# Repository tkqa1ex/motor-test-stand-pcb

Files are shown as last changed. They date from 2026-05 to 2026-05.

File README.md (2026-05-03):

# Motor Test Stand PCB

This repository contains the PCB design for a DC motor test stand.

## Features
- Current measurement (INA219 / ACS758)
- Temperature sensing (TMP117)
- Microcontroller interface (Arduino)

## Project Goal
Measure torque, efficiency, and electrical parameters of a DC motor using a generator-based load system.

## Files
- /pcb → PCB layout
- /schematic → circuit design
- /gerbers → manufacturing files

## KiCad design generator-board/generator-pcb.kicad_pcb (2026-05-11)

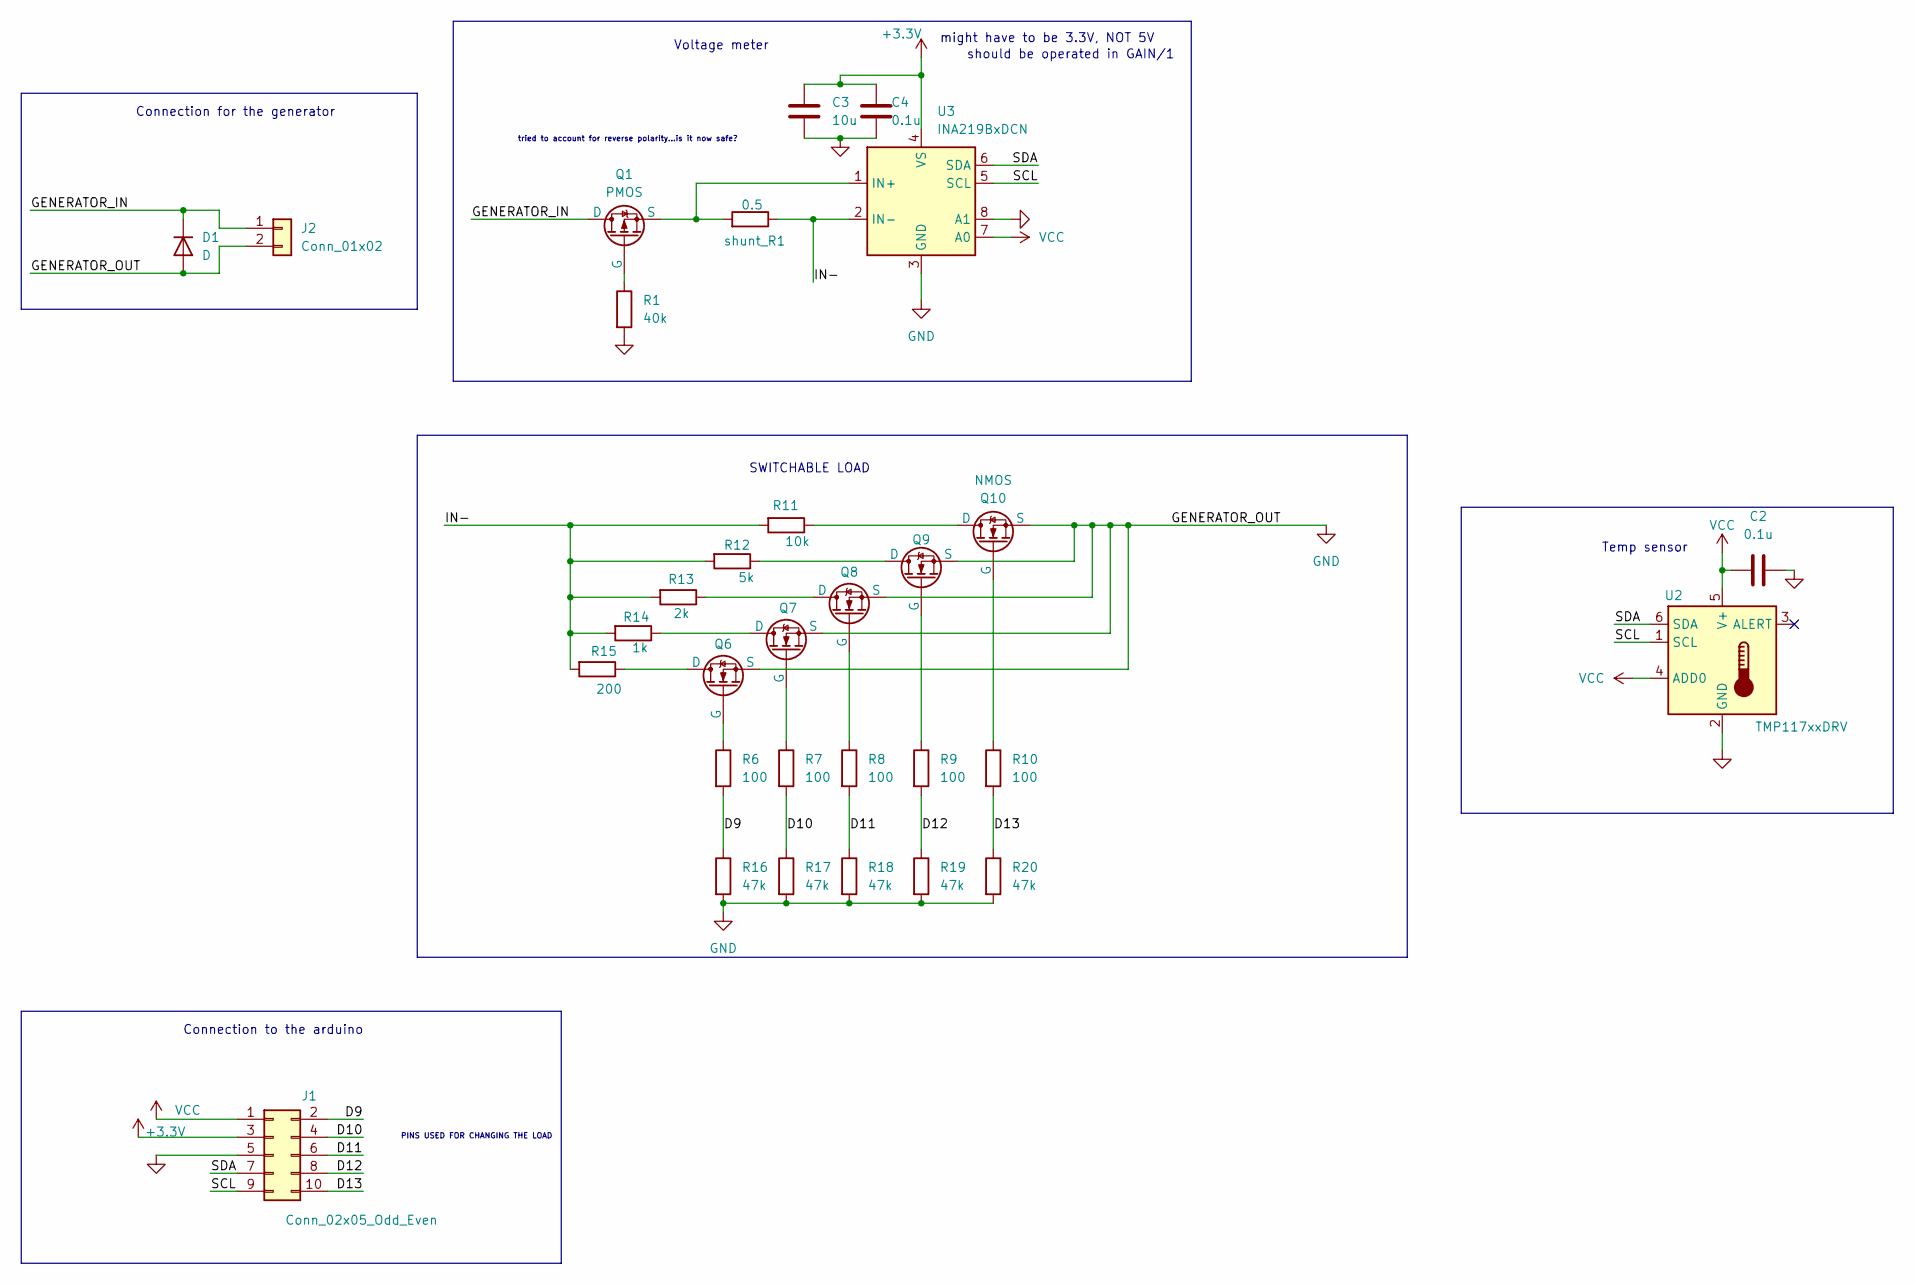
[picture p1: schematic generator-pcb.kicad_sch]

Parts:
C2, C4: 0.1u; CP_Radial_D10.0mm_P5.00mm
C3: 10u; CP_Radial_D10.0mm_P5.00mm
D1: D; D_DO-41_SOD81_P10.16mm_Horizontal
J1: Conn_02x05_Odd_Even; PinHeader_2x05_P2.54mm_Vertical
J2: Conn_01x02; PinHeader_1x02_P2.54mm_Vertical
Q1: PMOS; TO-220-3_Vertical
Q6, Q7, Q8, Q9, Q10: NMOS; TO-220-3_Vertical
R1: 40k; R_Axial_DIN0207_L6.3mm_D2.5mm_P7.62mm_Horizontal
R6, R7, R8, R9, R10: 100; R_Axial_DIN0207_L6.3mm_D2.5mm_P7.62mm_Horizontal
R11: 10k; R_Axial_DIN0207_L6.3mm_D2.5mm_P7.62mm_Horizontal
R12: 5k; R_Axial_DIN0207_L6.3mm_D2.5mm_P7.62mm_Horizontal
R13: 2k; R_Axial_DIN0207_L6.3mm_D2.5mm_P7.62mm_Horizontal
R14: 1k; R_Axial_DIN0207_L6.3mm_D2.5mm_P7.62mm_Horizontal
R15: 200; R_Axial_DIN0207_L6.3mm_D2.5mm_P7.62mm_Horizontal
R16, R17, R18, R19, R20: 47k; R_Axial_DIN0207_L6.3mm_D2.5mm_P7.62mm_Horizontal
U2: TMP117xxDRV; WSON-6-1EP_2x2mm_P0.65mm_EP1x1.6mm
U3: INA219BxDCN; SOT-23-8
shunt_R1: 0.5; R_Axial_DIN0207_L6.3mm_D2.5mm_P10.16mm_Horizontal

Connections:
+3.3V: C3.1, C4.1, J1.3, U3.4 (VS)
/D9: J1.2, R6.2, R16.1
/D10: J1.4, R7.2, R17.1
/D11: J1.6, R8.2, R18.1
/D12: J1.8, R9.2, R19.1
/D13: J1.10, R10.2, R20.1
/GENERATOR_IN: D1.1 (K), J2.1, Q1.1 (D)
/IN-: R11.2, R12.2, R13.2, R14.2, R15.2, U3.2 (IN-), shunt_R1.1
/SCL: J1.9, U2.1 (SCL), U3.5 (SCL)
/SDA: J1.7, U2.6 (SDA), U3.6 (SDA)
GND: C2.2, C3.2, C4.2, D1.2 (A), J1.5, J2.2, Q6.3 (S), Q7.3 (S), Q8.3 (S), Q9.3 (S), Q10.3 (S), R1.2, R16.2, R17.2, R18.2, R19.2, R20.2, U2.2 (GND), U3.3 (GND), U3.8 (A1)
unnamed: Q1.2 (G), R1.1
unnamed: Q1.3 (S), U3.1 (IN+), shunt_R1.2
unnamed: Q6.1 (D), R15.1
unnamed: Q6.2 (G), R6.1
unnamed: Q7.1 (D), R14.1
unnamed: Q7.2 (G), R7.1
unnamed: Q8.1 (D), R13.1
unnamed: Q8.2 (G), R8.1
unnamed: Q9.1 (D), R12.1
unnamed: Q9.2 (G), R9.1
unnamed: Q10.1 (D), R11.1
unnamed: Q10.2 (G), R10.1
VCC: C2.1, J1.1, U2.4 (ADD0), U2.5 (V+), U3.7 (A0)

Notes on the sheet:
Voltage meter
tried to account for reverse polarity...is it now safe?
might have to be 3.3V, NOT 5V
Temp sensor
SWITCHABLE LOAD
Connection for the generator
should be operated in GAIN/1
Connection to the arduino
PINS USED FOR CHANGING THE LOAD

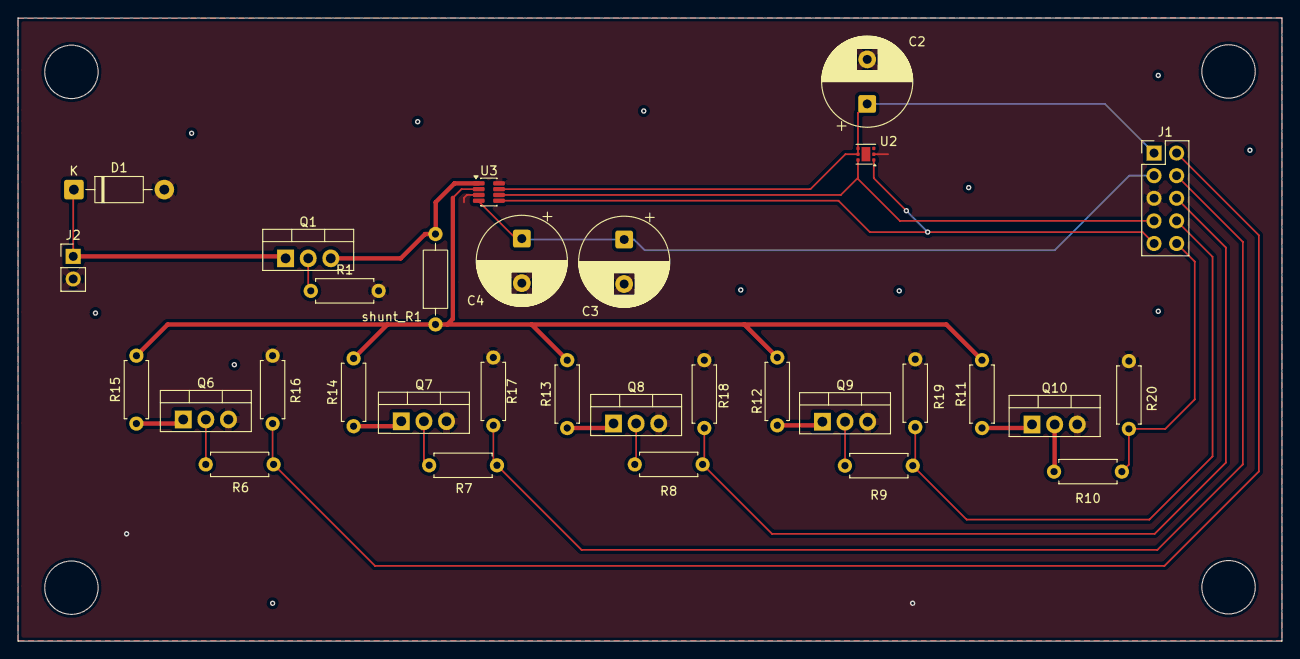
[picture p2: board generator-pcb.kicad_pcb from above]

Board: 2 copper layers, 142.0 x 70.0 mm, 31 parts (0 on the bottom side), 24 nets.

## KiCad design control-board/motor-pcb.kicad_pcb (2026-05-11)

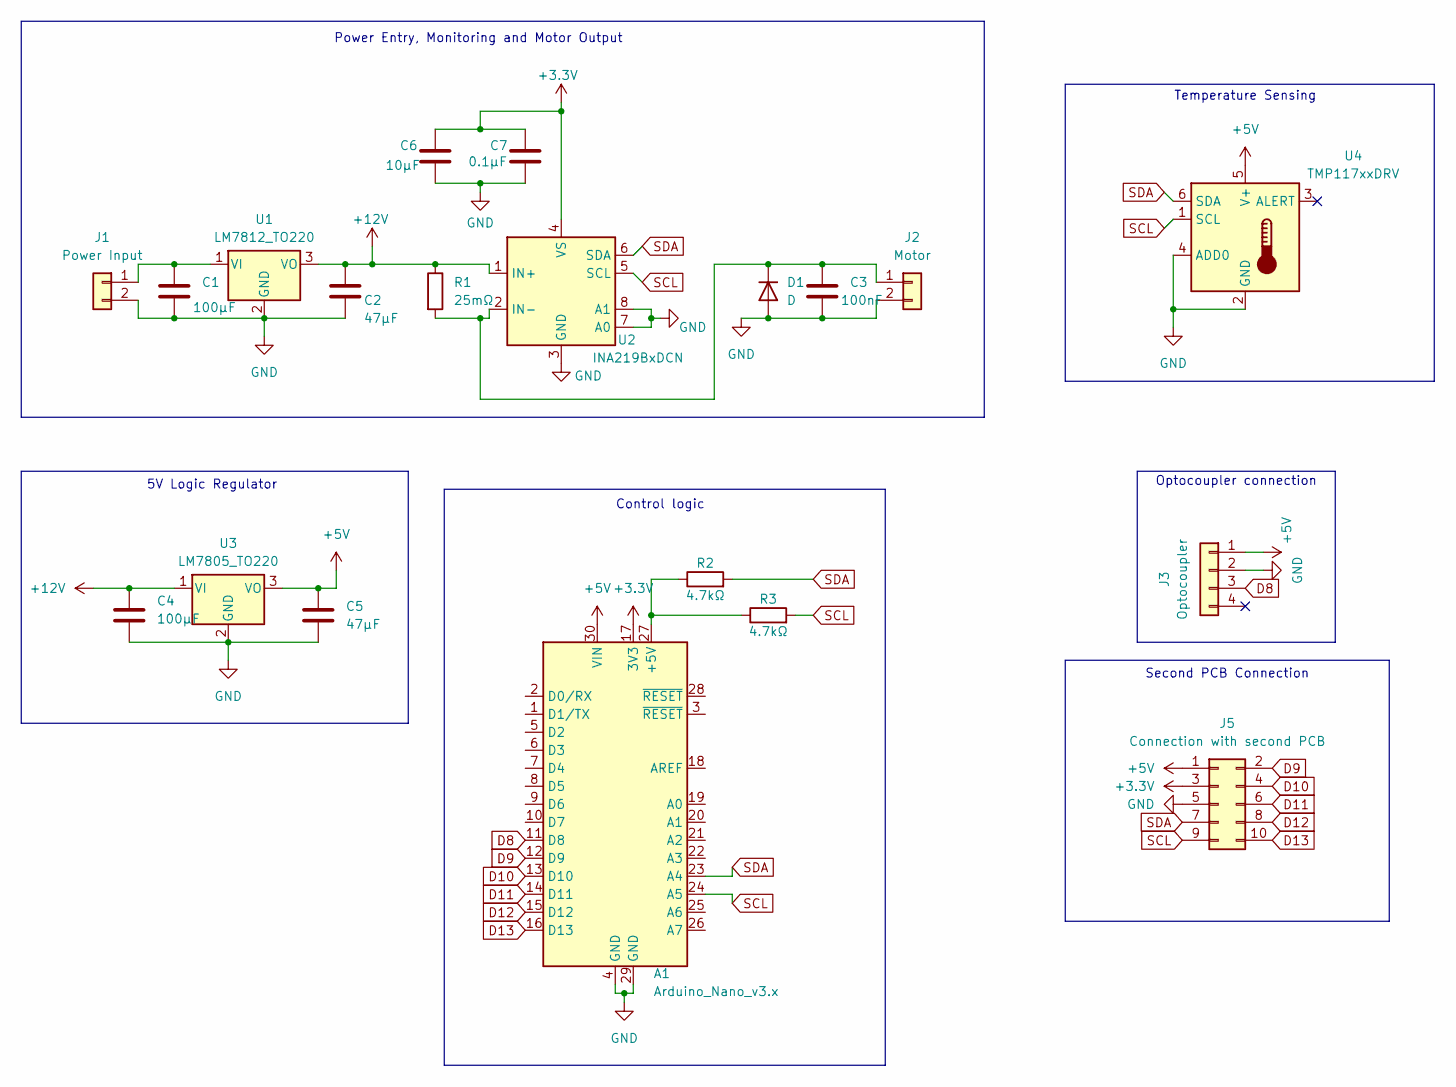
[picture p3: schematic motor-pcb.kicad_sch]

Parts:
A1: Arduino_Nano_v3.x; Arduino_Nano
C1, C4: 100µF; CP_Radial_D8.0mm_P3.50mm
C2, C5: 47µF; CP_Radial_D6.3mm_P2.50mm
C3: 100nF; C_Disc_D5.0mm_W2.5mm_P2.50mm
C6: 10µF; CP_Radial_D5.0mm_P2.00mm
C7: 0.1µF; C_Disc_D5.0mm_W2.5mm_P2.50mm
D1: D; D_DO-41_SOD81_P10.16mm_Horizontal
J1: Power Input; TerminalBlock_CUI_TB007-508-02_1x02_P5.08mm_Horizontal
J2: Motor; TerminalBlock_CUI_TB007-508-02_1x02_P5.08mm_Horizontal
J3: Optocoupler; PinHeader_1x04_P2.54mm_Vertical
J5: Connection with second PCB; PinHeader_2x05_P2.54mm_Vertical
R1: 25mΩ; R_Axial_DIN0414_L11.9mm_D4.5mm_P15.24mm_Horizonta
R2: 4.7kΩ; R_Axial_DIN0207_L6.3mm_D2.5mm_P10.16mm_Horizontal
R3: 4.7kΩ; R_Axial_DIN0207_L6.3mm_D2.5mm_P7.62mm_Horizontal
U1: LM7812_TO220; TO-220-3_Vertical
U2: INA219BxDCN; SOT-23-8
U3: LM7805_TO220; TO-220-3_Vertical
U4: TMP117xxDRV; WSON-6-1EP_2x2mm_P0.65mm_EP1x1.6mm

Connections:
+3.3V: A1.17 (3V3), C6.1, C7.1, J5.3, U2.4 (VS)
+5V: A1.30 (VIN), C5.1, J3.1, J5.1, U3.3 (VO), U4.5 (V+)
+12V: C2.1, C4.1, R1.1, U1.3 (VO), U2.1 (IN+), U3.1 (VI)
D8: A1.11 (D8), J3.3
D9: A1.12 (D9), J5.2
D10: A1.13 (D10), J5.4
D11: A1.14 (D11), J5.6
D12: A1.15 (D12), J5.8
D13: A1.16 (D13), J5.10
GND: A1.4 (GND), A1.29 (GND), C1.2, C2.2, C3.2, C4.2, C5.2, C6.2, C7.2, D1.2 (A), J1.2, J2.2, J3.2, J5.5, U1.2 (GND), U2.3 (GND), U2.7 (A0), U2.8 (A1), U3.2 (GND), U4.2 (GND), U4.4 (ADD0)
unnamed: A1.27 (+5V), R2.1, R3.1
unnamed: C3.1, D1.1 (K), J2.1, R1.2, U2.2 (IN-)
unnamed: C1.1, J1.1, U1.1 (VI)
SCL: A1.24 (A5), J5.9, R3.2, U2.5 (SCL), U4.1 (SCL)
SDA: A1.23 (A4), J5.7, R2.2, U2.6 (SDA), U4.6 (SDA)

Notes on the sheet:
Temperature Sensing
Control logic
Optocoupler connection
Power Entry, Monitoring and Motor Output
Second PCB Connection
5V Logic Regulator

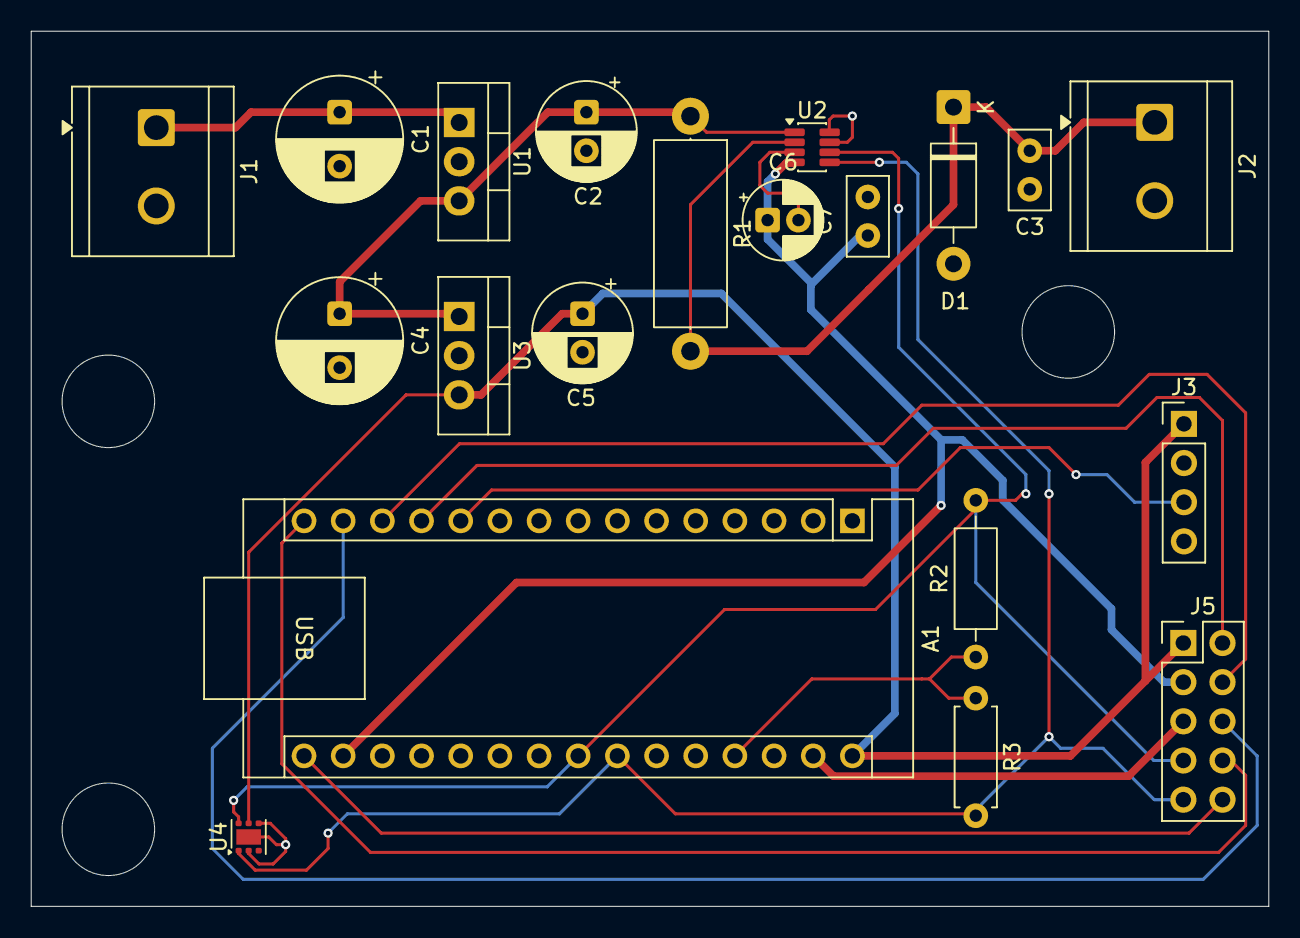
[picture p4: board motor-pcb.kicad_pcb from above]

Board: 2 copper layers, 80.2 x 56.8 mm, 20 parts (0 on the bottom side), 15 nets.

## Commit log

2026-05-03 Updated PCB layout: improved routing and component placement
    [motor-pcb.kicad_pcb]
2026-05-05 Updated shunt resistor value, footprints, layout
    [motor-pcb.kicad_pcb, motor-pcb.kicad_sch]
2026-05-11 Final Pcb
    [motor-pcb.kicad_pcb]
2026-05-11 Generator Board PCB
    Load control, Current and Voltage measures, Temperature measure
    [generator-pcb.kicad_pcb, generator-pcb.kicad_sch]
2026-05-11 Create Control-Board
2026-05-11 Moving files to control-board folder
    [motor-pcb.kicad_pcb, motor-pcb.kicad_sch]
2026-05-11 Moving files to generator-board
    [generator-pcb.kicad_pcb, generator-pcb.kicad_sch]
